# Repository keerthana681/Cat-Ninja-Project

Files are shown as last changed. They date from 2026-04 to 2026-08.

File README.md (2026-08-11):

# Cat Ninja Handheld Console Game
 
A handheld gaming console built from scratch for UT Austin's ECE319H (Introduction to Embedded Systems), featuring a custom PCB, dual-LCD displays, and an interrupt-driven game engine.
 
## Overview
 
Cat Ninja is a fully custom embedded gaming handheld built around the TI MSPM0 microcontroller. The project spans the full hardware-software stack: a custom-designed PCB, analog input sampling via joystick and slide potentiometer, a discrete DAC for in-game sound, and a real-time game engine driven by hardware timers and interrupts.
 
## Features
 
- **Custom PCB** designed in KiCad, integrating the TI MSPM0 microcontroller with dual-LCD displays and a joystick interface
- **Dual-LCD setup** — one screen renders the live game, the other displays the score and a reactive cat sprite (happy when fish are sliced, sad when a bomb is hit or a life is lost)
- **Original hand-drawn sprite art** for the cat cursor, fish, sliced-fish states, and bombs
- **Analog input sampling** via ADC for the joystick (menu navigation and cursor movement) and slide potentiometer (in-game volume control)
- **5-bit binary-weighted DAC** for real-time sound effects (slicing, explosions, and more)
- **Interrupt-driven game engine** written in C++, using SysTick and TimerG12 for periodic game logic, rendering, and input polling
- **Finite state machine (FSM) architecture** driving the title menu, settings, gameplay, pause, and game-over screens
## How to Play
 
**Menu Navigation**
- On the title screen, move the joystick to switch between **Info**, **Settings**, and **Play**
- One button **selects** the highlighted option; the other button **goes back** to the previous screen
- **Info** explains how to play
- **Settings** lets you change the display language (English/Spanish)
**Gameplay**
- Move the cat paw cursor around the screen using the joystick
- Press the select button to **slice** — this triggers a slicing sound and swaps the fish sprite to its sliced state
- Fish rise and fall across the screen at random; slice them to score points
- Bombs appear at random alongside the fish — avoid slicing these
- You have **3 lives**. You lose a life if you let a fish fall unsliced, or if you slice a bomb (which also triggers an explosion sound)
- When you run out of lives, the game ends with a crying-cat sound effect
- The volume of in-game sound effects is controlled in real time by the slide potentiometer
## Hardware
 
- TI MSPM0 microcontroller
- Dual-LCD display setup
- Joystick + slide potentiometer analog inputs
- Custom binary-weighted DAC circuit for audio output
- PCB designed and fabricated for this project (see `/hardware` for KiCad files and schematics)
## Software
 
- Core game engine written in C++
- SysTick and TimerG12 used for periodic, interrupt-driven task scheduling
- ADC driver for analog input sampling
- DAC output driver for sound playback
## Team
 
Built by Keerthana Mangalpally and Kaitlyn Chen for ECE319H at UT Austin.
 
## Acknowledgments & License
 
This project uses hardware driver code adapted from course materials provided by Dr. Jonathan Valvano for UT Austin's embedded systems curriculum, used under the license below.
 
```
Simplified BSD License (FreeBSD License)
Copyright © 2025, Jonathan Valvano, All rights reserved.
 
Redistribution and use in source and binary forms, with or without modification,
are permitted provided that the following conditions are met:
 
1. Redistributions of source code must retain the above copyright notice,
   this list of conditions and the following disclaimer.
2. Redistributions in binary form must reproduce the above copyright notice,
   this list of conditions and the following disclaimer in the documentation
   and/or other materials provided with the distribution.
 
THIS SOFTWARE IS PROVIDED BY THE COPYRIGHT HOLDERS AND CONTRIBUTORS "AS IS"
AND ANY EXPRESS OR IMPLIED WARRANTIES, INCLUDING, BUT NOT LIMITED TO, THE
IMPLIED WARRANTIES OF MERCHANTABILITY AND FITNESS FOR A PARTICULAR PURPOSE
ARE DISCLAIMED. IN NO EVENT SHALL THE COPYRIGHT OWNER OR CONTRIBUTORS BE
LIABLE FOR ANY DIRECT, INDIRECT, INCIDENTAL, SPECIAL, EXEMPLARY, OR CONSEQUENTIAL
DAMAGES (INCLUDING, BUT NOT LIMITED TO, PROCUREMENT OF SUBSTITUTE GOODS OR SERVICES;
LOSS OF USE, DATA, OR PROFITS; OR BUSINESS INTERRUPTION) HOWEVER CAUSED
AND ON ANY THEORY OF LIABILITY, WHETHER IN CONTRACT, STRICT LIABILITY,
OR TORT (INCLUDING NEGLIGENCE OR OTHERWISE) ARISING IN ANY WAY OUT OF THE
USE OF THIS SOFTWARE, EVEN IF ADVISED OF THE POSSIBILITY OF SUCH DAMAGE.
 
The views and conclusions contained in the software and documentation are
those of the authors and should not be interpreted as representing official
policies, either expressed or implied, of the FreeBSD Project.
```
 
For more information on the original course materials, see [Dr. Valvano's course page](http://users.ece.utexas.edu/~valvano/).

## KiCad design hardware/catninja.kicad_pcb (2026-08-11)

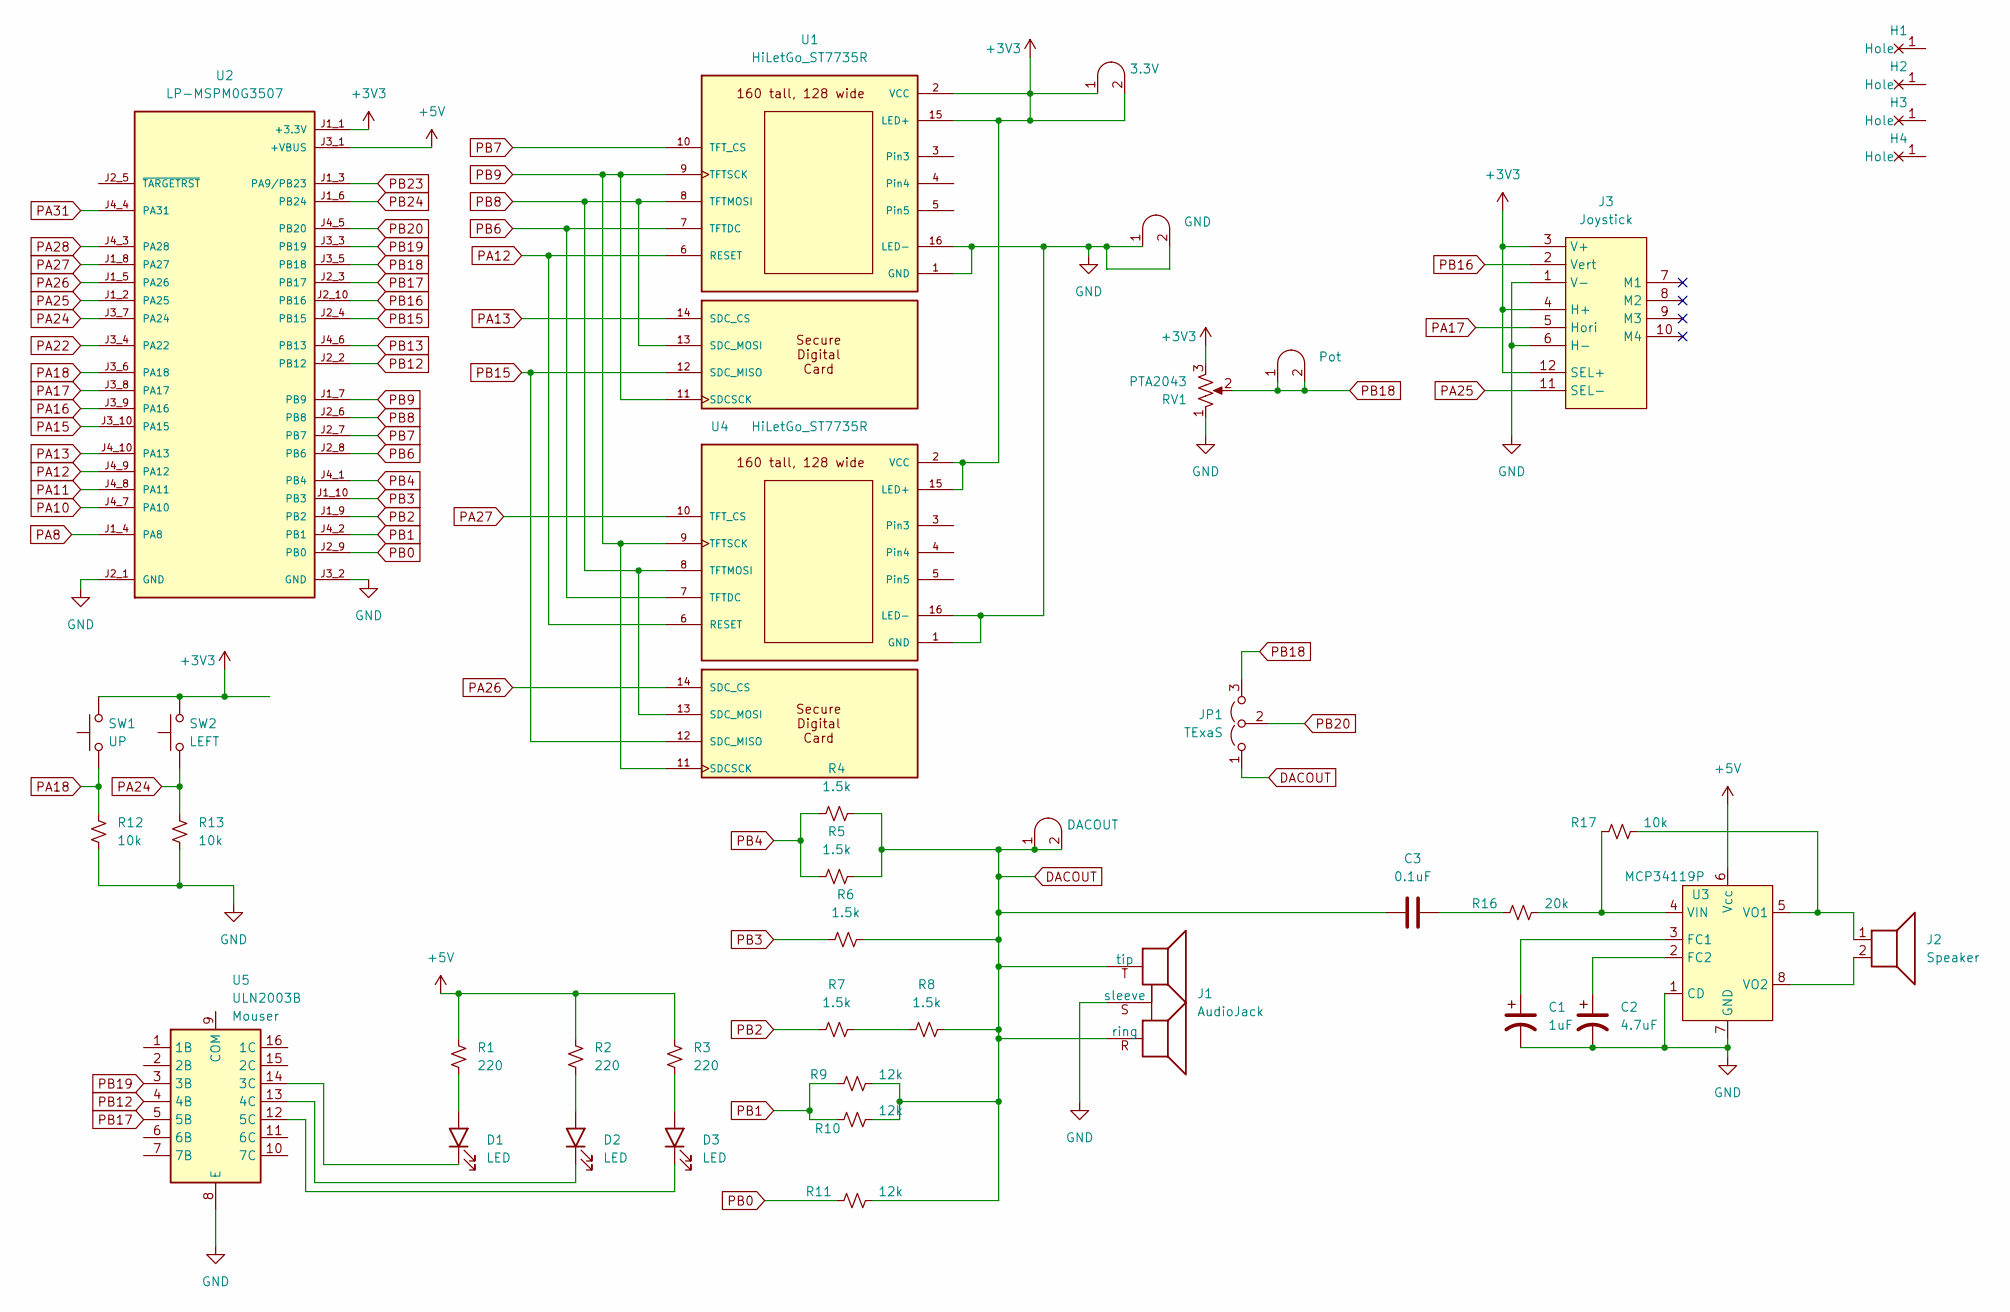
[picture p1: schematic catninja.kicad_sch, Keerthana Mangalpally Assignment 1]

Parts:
C1: 1uF; CP_Radial_Tantal200mil
C2: 4.7uF; CP_Radial_Tantal200mil
C3: 0.1uF; C_Axial_200mil
D1, D2, D3: LED; LED_D5.0mm
H1, H2, H3, H4: MountingHole_4_40
J1: AudioJack; Jack_3.5mm_CUI_SJ1-3523N_Horizontal
J2: Speaker; PinHeader_1x02_P2.54mm_Vertical
J3: Joystick; SparkfunJoystick
J4: Pot; Testpoint_1x02_P2.54mm
J6: GND; Testpoint_1x02_P2.54mm
J7: DACOUT; Testpoint_1x02_P2.54mm
JP1: TExaS; PinHeader_1x03_P2.54mm_Vertical
R1, R2, R3: 220; R_Axial_DIN0204_L3.6mm_D1.6mm_P7.62mm_Horizontal
R4, R5, R6, R7, R8: 1.5k; R_Axial_DIN0204_L3.6mm_D1.6mm_P7.62mm_Horizontal
R9, R10, R11: 12k; R_Axial_DIN0204_L3.6mm_D1.6mm_P7.62mm_Horizontal
R12, R13, R17: 10k; R_Axial_DIN0204_L3.6mm_D1.6mm_P7.62mm_Horizontal
R16: 20k; R_Axial_DIN0204_L3.6mm_D1.6mm_P7.62mm_Horizontal
RV1: PTA2043; PTA2043pot
SW1: UP; SW_PUSH_6mm
SW2: LEFT; SW_PUSH_6mm
TP1: 3.3V; Testpoint_1x02_P2.54mm
U1, U4: HiLetGo_ST7735R; hiletgo_st7735r
U2: LP-MSPM0G3507; ti_LP_MSPM0G3507
U3: MCP34119P; DIP-8_W7.62mm_LongPads
U5: ULN2003B; DIP-16_W7.62mm

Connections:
+3V3: J3.3 (V+), J3.4 (H+), J3.12 (SEL+), RV1.3, SW1.2, SW2.2, TP1.1 (A), TP1.2 (B), U1.2 (VCC), U1.15 (LED+), U2.J1_1 (+3.3V), U4.2 (VCC), U4.15 (LED+)
+5V: R1.1, R2.1, R3.1, U2.J3_1 (+VBUS), U3.6 (Vcc)
DACOUT: C3.1, J1.R (ring), J1.T (tip), J7.1 (A), J7.2 (B), JP1.1 (A), R4.1, R5.1, R6.1, R8.1, R9.1, R10.1, R11.1
GND: C1.2, C2.2, J1.S (sleeve), J3.1 (V-), J3.6 (H-), J6.1 (A), J6.2 (B), R12.2, R13.2, RV1.1, U1.1 (GND), U1.16 (LED-), U2.J2_1 (GND), U2.J3_2 (GND), U3.1 (CD), U3.7 (GND), U4.1 (GND), U4.16 (LED-), U5.8 (E)
unnamed: C3.2, R16.2
unnamed: D1.2 (A), R1.2
unnamed: D1.1 (K), U5.14 (3C)
unnamed: D2.2 (A), R2.2
unnamed: D2.1 (K), U5.13 (4C)
unnamed: D3.2 (A), R3.2
unnamed: D3.1 (K), U5.12 (5C)
unnamed: R7.1, R8.2
unnamed: C1.1, U3.3 (FC1)
unnamed: C2.1, U3.2 (FC2)
unnamed: R16.1, R17.2, U3.4 (VIN)
unnamed: J2.1, R17.1, U3.5 (VO1)
unnamed: J2.2, U3.8 (VO2)
PA8: U2.J1_4 (PA8)
PA10: U2.J4_7 (PA10)
PA11: U2.J4_8 (PA11)
PA12: U1.6 (RESET), U2.J4_9 (PA12), U4.6 (RESET)
PA13: U1.14 (SDC_CS), U2.J4_10 (PA13)
PA15: U2.J3_10 (PA15)
PA16: U2.J3_9 (PA16)
PA17: J3.5 (Hori), U2.J3_8 (PA17)
PA18: R12.1, SW1.1, U2.J3_6 (PA18)
PA22: U2.J3_4 (PA22)
PA24: R13.1, SW2.1, U2.J3_7 (PA24)
PA25: J3.11 (SEL-), U2.J1_2 (PA25)
PA26: U2.J1_5 (PA26), U4.14 (SDC_CS)
PA27: U2.J1_8 (PA27), U4.10 (TFT_CS)
PA28: U2.J4_3 (PA28)
PA31: U2.J4_4 (PA31)
PB0: R11.2, U2.J2_9 (PB0)
PB1: R9.2, R10.2, U2.J4_2 (PB1)
PB2: R7.2, U2.J1_9 (PB2)
PB3: R6.2, U2.J1_10 (PB3)
PB4: R4.2, R5.2, U2.J4_1 (PB4)
PB6: U1.7 (TFTDC), U2.J2_8 (PB6), U4.7 (TFTDC)
PB7: U1.10 (TFT_CS), U2.J2_7 (PB7)
PB8: U1.8 (TFTMOSI), U1.13 (SDC_MOSI), U2.J2_6 (PB8), U4.8 (TFTMOSI), U4.13 (SDC_MOSI)
PB9: U1.9 (TFTSCK), U1.11 (SDCSCK), U2.J1_7 (PB9), U4.9 (TFTSCK), U4.11 (SDCSCK)
PB12: U2.J2_2 (PB12), U5.4 (4B)
PB13: U2.J4_6 (PB13)
PB15: U1.12 (SDC_MISO), U2.J2_4 (PB15), U4.12 (SDC_MISO)
PB16: J3.2 (Vert), U2.J2_10 (PB16)
PB17: U2.J2_3 (PB17), U5.5 (5B)
PB18: J4.1 (A), J4.2 (B), JP1.3 (B), RV1.2, U2.J3_5 (PB18)
PB19: U2.J3_3 (PB19), U5.3 (3B)
PB20: JP1.2 (C), U2.J4_5 (PB20)
PB23: U2.J1_3 (PA9/PB23)
PB24: U2.J1_6 (PB24)

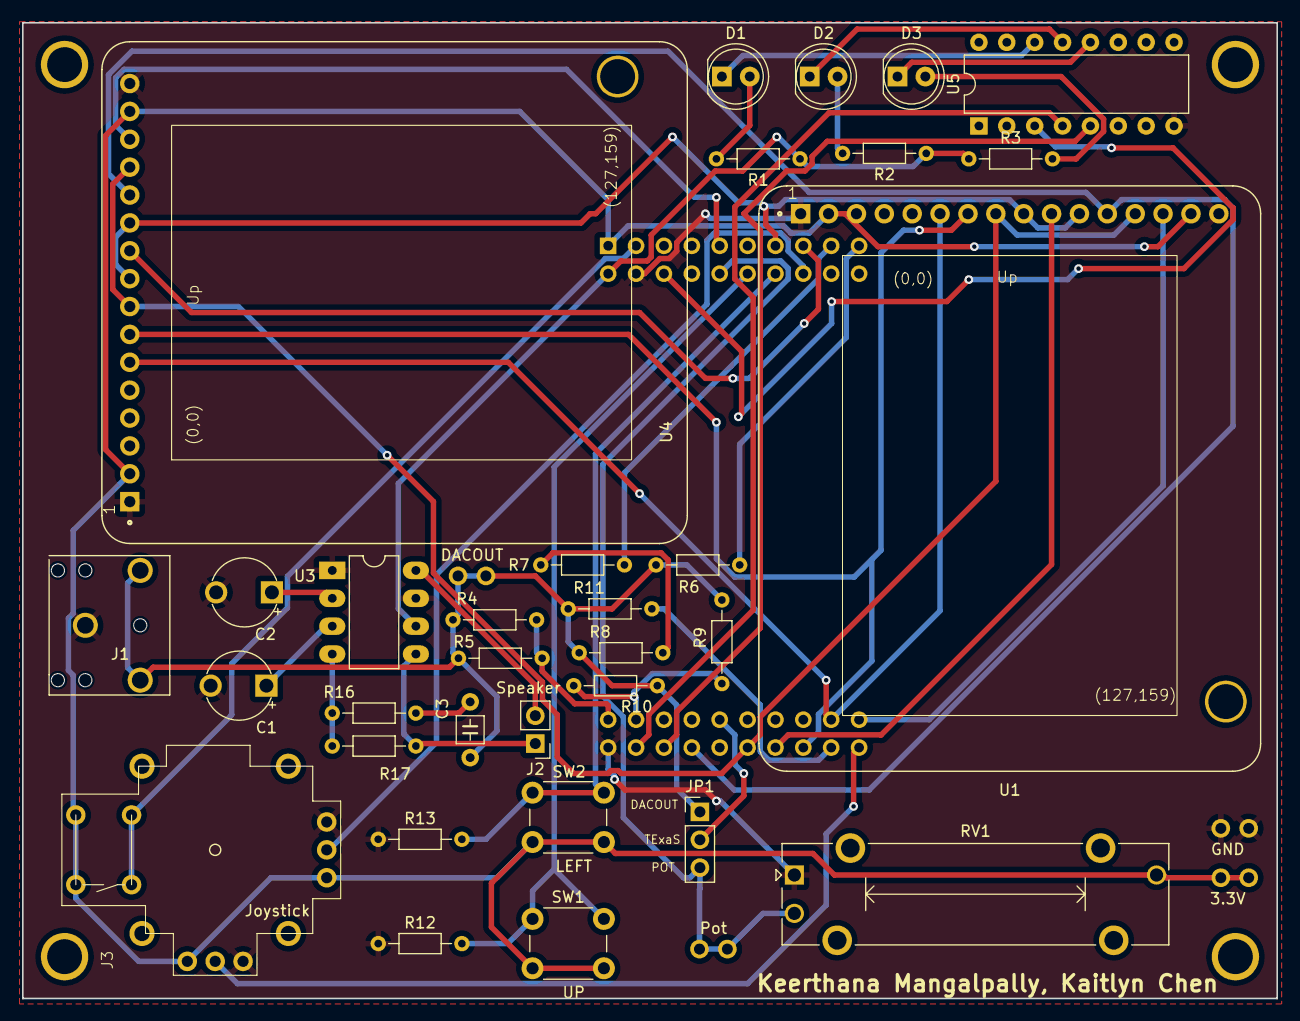
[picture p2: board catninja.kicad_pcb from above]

Board: 2 copper layers, 114.3 x 88.9 mm, 41 parts (1 on the bottom side), 41 nets.

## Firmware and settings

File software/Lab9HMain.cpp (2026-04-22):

// Lab9HMain.cpp
// Runs on MSPM0G3507
// Lab 9 ECE319H
// Kaitlyn Chen
// Last Modified: April 21, 2026

//made files
#include "game.h"
#include "LCD2.h"

#include <stdio.h>
#include <stdint.h>
#include <ti/devices/msp/msp.h>
#include "../inc/ST7735.h"
#include "../inc/Clock.h"
#include "../inc/LaunchPad.h"
#include "../inc/TExaS.h"
#include "../inc/Timer.h"
#include "../inc/SlidePot.h"
#include "../inc/DAC5.h"
// #include "SmallFont.h"
#include "LED.h"
#include "Switch.h"
#include "Sound.h"
#include "images/images.h"
#include "Timer.h"
#include "JoyStick.h"
#include "../inc/SPI.h"

extern "C" void __disable_irq(void);
extern "C" void __enable_irq(void);
extern "C" void TIMG12_IRQHandler(void);

extern "C" {
    #include "ADC.h" 
}

// Fault diagnostics exposed as globals for the debugger.
// If execution lands in a fault/default handler, inspect these values first.
extern "C" volatile uint32_t g_fault_vector = 0;
extern "C" volatile uint32_t g_fault_pc = 0;
extern "C" volatile uint32_t g_fault_lr = 0;
extern "C" volatile uint32_t g_fault_sp = 0;
extern "C" volatile uint32_t g_fault_ipsr = 0;
extern "C" volatile uint32_t g_fault_xpsr = 0;

extern "C" void Fault_Capture(uint32_t *sp){
  g_fault_sp = (uint32_t)sp;
  g_fault_ipsr = __get_IPSR();
  g_fault_vector = g_fault_ipsr & 0x1FFu;
  if(sp){
    g_fault_pc = sp[6];   // stacked PC
    g_fault_lr = sp[5];   // stacked LR
    g_fault_xpsr = sp[7]; // stacked xPSR
  }else{
    g_fault_pc = 0;
    g_fault_lr = 0;
    g_fault_xpsr = 0;
  }
}

extern "C" void HardFault_Handler(void){
  __disable_irq();
  Fault_Capture((uint32_t *)__get_MSP());
  while(1){
  }
}

extern "C" void Default_Handler(void){
  __disable_irq();
  Fault_Capture((uint32_t *)__get_MSP());
  while(1){
  }
}
// ****note to ECE319K students****
// the data sheet says the ADC does not work when clock is 80 MHz
// however, the ADC seems to work on my boards at 80 MHz
// I suggest you try 80MHz, but if it doesn't work, switch to 40MHz
void PLL_Init(void){ // set phase lock loop (PLL)
  // Clock_Init40MHz(); // run this line for 40MHz
  Clock_Init80MHz();   // run this line for 80MHz
}

uint32_t M=1;
uint32_t Random32(void){
  M = 1664525*M+1013904223;
  return M;
}
uint32_t Random(uint32_t n){
  return (Random32()>>16)%n;
}

SlidePot Sensor(1500,0); // copy calibration from Lab 7

// games  engine runs at 30Hz
extern "C" void TIMG12_IRQHandler(void){uint32_t pos,msg;
  if((TIMG12->CPU_INT.IIDX) == 1){ // this will acknowledge
    GPIOB->DOUTTGL31_0 = GREEN; // toggle PB27 (minimally intrusive debugging)
    GPIOB->DOUTTGL31_0 = GREEN; // toggle PB27 (minimally intrusive debugging)
// game engine goes here
    // 1) sample slide pot
    // 2) read input switches
    // 3) move sprites
    // 4) start sounds
    // 5) set semaphore
    // NO LCD OUTPUT IN INTERRUPT SERVICE ROUTINES
    Semaphore = 1;
    GPIOB->DOUTTGL31_0 = GREEN; // toggle PB27 (minimally intrusive debugging)
  }
}
uint8_t TExaS_LaunchPadLogicPB27PB26(void){
  return (0x80|((GPIOB->DOUT31_0>>26)&0x03));
}

typedef enum {English, Spanish, Portuguese, French} Language_t;
Language_t myLanguage=English;
typedef enum {HELLO, GOODBYE, LANGUAGE} phrase_t;
const char Hello_English[] ="Hello";
const char Hello_Spanish[] ="\xADHola!";
const char Hello_Portuguese[] = "Ol\xA0";
const char Hello_French[] ="All\x83";
const char Goodbye_English[]="Goodbye";
const char Goodbye_Spanish[]="Adi\xA2s";
const char Goodbye_Portuguese[] = "Tchau";
const char Goodbye_French[] = "Au revoir";
const char Language_English[]="English";
const char Language_Spanish[]="Espa\xA4ol";
const char Language_Portuguese[]="Portugu\x88s";
const char Language_French[]="Fran\x87" "ais";
const char *Phrases[3][4]={
  {Hello_English,Hello_Spanish,Hello_Portuguese,Hello_French},
  {Goodbye_English,Goodbye_Spanish,Goodbye_Portuguese,Goodbye_French},
  {Language_English,Language_Spanish,Language_Portuguese,Language_French}
};
// use main1 to observe special characters
int main1(void){ // main1
    char l;
  __disable_irq();
  PLL_Init(); // set bus speed
  LaunchPad_Init();
  ST7735_InitPrintf(INITR_BLACKTAB); // INITR_REDTAB for AdaFruit, INITR_BLACKTAB for HiLetGo
  ST7735_FillScreen(0x0000);            // set screen to black
  for(int myPhrase=0; myPhrase<= 2; myPhrase++){
    for(int myL=0; myL<= 3; myL++){
         ST7735_OutString((char *)Phrases[LANGUAGE][myL]);
      ST7735_OutChar(' ');
         ST7735_OutString((char *)Phrases[myPhrase][myL]);
      ST7735_OutChar(13);
    }
  }
  Clock_Delay1ms(3000);
  ST7735_FillScreen(0x0000);       // set screen to black
  l = 128;
  while(1){
    Clock_Delay1ms(2000);
    for(int j=0; j < 3; j++){
      for(int i=0;i<16;i++){
        ST7735_SetCursor(7*j+0,i);
        ST7735_OutUDec(l);
        ST7735_OutChar(' ');
        ST7735_OutChar(' ');
        ST7735_SetCursor(7*j+4,i);
        ST7735_OutChar(l);
        l++;
      }
    }
  }
}

// // use main2 to observe graphics
// int main2(void){ // main2
//   __disable_irq();
//   PLL_Init(); // set bus speed
//   LaunchPad_Init();
//   ST7735_InitPrintf(INITR_BLACKTAB); // INITR_REDTAB for AdaFruit, INITR_BLACKTAB for HiLetGo
//   ST7735_FillScreen(ST7735_BLACK);
//   // ST7735_DrawBitmap(22, 159, PlayerShip0, 18,8); // player ship bottom
//   // ST7735_DrawBitmap(53, 151, Bunker0, 18,5);
//   // ST7735_DrawBitmap(42, 159, PlayerShip1, 18,8); // player ship bottom
//   // ST7735_DrawBitmap(62, 159, PlayerShip2, 18,8); // player ship bottom
//   // ST7735_DrawBitmap(82, 159, PlayerShip3, 18,8); // player ship bottom
//   // ST7735_DrawBitmap(0, 9, SmallEnemy10pointA, 16,10);
//   // ST7735_DrawBitmap(20,9, SmallEnemy10pointB, 16,10);
//   // ST7735_DrawBitmap(40, 9, SmallEnemy20pointA, 16,10);
//   // ST7735_DrawBitmap(60, 9, SmallEnemy20pointB, 16,10);
//   // ST7735_DrawBitmap(80, 9, SmallEnemy30pointA, 16,10);

//   for(uint32_t t=500;t>0;t=t-5){
//     SmallFont_OutVertical(t,104,6); // top left
//     Clock_Delay1ms(50);              // delay 50 msec
//   }
//   ST7735_FillScreen(0x0000);   // set screen to black
//   ST7735_SetCursor(1, 1);
//   ST7735_OutString((char *)"GAME OVER");
//   ST7735_SetCursor(1, 2);
//   ST7735_OutString((char *)"Nice try,");
//   ST7735_SetCursor(1, 3);
//   ST7735_OutString((char *)"Earthling!");
//   ST7735_SetCursor(2, 4);
//   ST7735_OutUDec(1234);
//   while(1){
//   }
// }

// use main3 to test switches and LEDs
int main3(void){ // main3
  __disable_irq();
  PLL_Init(); // set bus speed
  LaunchPad_Init();
  Switch_Init(); // initialize switches
  LED_Init(); // initialize LED
  while(1){
    // write code to test switches and LEDs

  }
}
// use main4 to test sound outputs
// int main4(void){ uint32_t last1=0,last2=0;
//   __disable_irq();
//   PLL_Init(); // set bus speed
//   LaunchPad_Init();
//   Switch_Init(); // initialize switches
//   LED_Init(); // initialize LED
//   Sound_Init();  // initialize sound
//   TExaS_Init(ADC0,6,0); // ADC1 channel 6 is PB20, TExaS scope
//   __enable_irq();
//   while(1){
//     uint8_t btn1 = (GPIOA->DIN31_0 >> 24) & 0x01;
//     uint8_t btn2 = (GPIOA->DIN31_0 >> 25) & 0x01;
//     if((last1 == 0)&&(btn1 == 1)){
//       Sound_Shoot();
//     }
//     if((last2 == 0)&&(btn2 == 1)){
//       Sound_Killed();
//     }
//     last1 = btn1;
//     last2 = btn2;
//   }
// }
//tests led functions 
int main8(void){
    __disable_irq();
    PLL_Init();
    LaunchPad_Init();
    LED_Init();
    __enable_irq();

    while(1){
        LED_SetLives(3);
        Clock_Delay1ms(500);
        LED_SetLives(2);
        Clock_Delay1ms(500);
        LED_SetLives(1);
        Clock_Delay1ms(500);
        LED_SetLives(0);
        Clock_Delay1ms(500);
    }
}
int main7(void){
    __disable_irq();
    PLL_Init();
    LaunchPad_Init();

    // LED pins: PB19, PB12, PB17 through ULN2003B
    IOMUX->SECCFG.PINCM[44] = 0x00000081;  // PB19
    IOMUX->SECCFG.PINCM[28] = 0x00000081;  // PB12
    IOMUX->SECCFG.PINCM[42] = 0x00000081;  // PB17
    GPIOB->DOE31_0 |= (1<<19) | (1<<12) | (1<<17);

    __enable_irq();

    // turn all on
    GPIOB->DOUTSET31_0 = (1<<19) | (1<<12) | (1<<17);

    while(1){
        GPIOB->DOUTTGL31_0 = (1<<19) | (1<<12) | (1<<17);
        Clock_Delay1ms(500);
    }
}
int main6(void){
    __disable_irq();
    PLL_Init();
    LaunchPad_Init();
    // configure PA15 as GPIO output
    IOMUX->SECCFG.PINCM[PA15INDEX] = 0x00000081;
    GPIOA->DOE31_0 |= (1<<15);
    __enable_irq();
    
    while(1){
        GPIOA->DOUTTGL31_0 = (1<<15); // toggle PA15
        Clock_Delay1ms(1); // ~500 Hz buzz
    }
}

int main9(void){
    __disable_irq();
    PLL_Init();
    LaunchPad_Init();
    ST7735_InitPrintf(INITR_BLACKTAB);
    // LCD2_Init();
    __enable_irq();

    while(1){
        SPI_SelectDisplay(SPI_DISPLAY_LCD1);
        ST7735_SetRotation(1);
        ST7735_FillScreen(ST7735_RED);
        ST7735_SetCursor(2, 2);
        ST7735_SetTextColor(ST7735_WHITE);
        ST7735_OutString((char*)"LCD1 ONLY");
        Clock_Delay1ms(1000);

        SPI_SelectDisplay(SPI_DISPLAY_LCD2);
        LCD2_FillScreen(LCD2_BLUE);
        Clock_Delay1ms(1000);
    }
}

// ALL ST7735 OUTPUT MUST OCCUR IN MAIN
// NOTE: ADC.h is already included above (wrapped in extern "C") — no second include needed.

int main(void){
    __disable_irq();
    PLL_Init();
    LaunchPad_Init();
    ST7735_InitPrintf(INITR_BLACKTAB);
    SPI_SelectDisplay(SPI_DISPLAY_LCD1);
    ST7735_SetRotation(1);
    ST7735_FillScreen(ST7735_BLACK);
    Sensor.Init();
    Switch_Init();
    LED_Init();
    Sound_Init();
    TExaS_Init(0,0,&TExaS_LaunchPadLogicPB27PB26);
    TimerG12_IntArm(80000000/30, 2);
    LCD2_Init();   // second display (portrait, PA26 CS) — must come after ST7735_InitPrintf
    Game_Init();
    Semaphore = 1; // render the first frame even if the timer has not fired yet
    __enable_irq();

    while(1){
      if(Semaphore){
        Semaphore = 0;
      } else {
        // Fall back to software pacing so startup does not deadlock if TIMG12 does not tick yet.
        Clock_Delay1ms(33);
      }

      // Read slide pot without resetting ADC1 (a full reset breaks the joystick).
      Sound_SetVolume(Joystick_ReadSlidePot());

      SPI_SelectDisplay(SPI_DISPLAY_LCD1);
      Game_UpdateFrame();

      uint32_t Input  = Game_GetInput();
      uint32_t nextS  = FSM[S].Next[Input];

      // Play meow whenever the player navigates to a new screen,
      // but not on game-over (Sound_Sad starts there instead).
      if(nextS != S && nextS != S_GAMEOVER){
          Sound_Meow();
      }

      S = nextS;
    }
}

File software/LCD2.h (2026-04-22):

// LCD2.h
// Driver for the second ST7735 display (portrait orientation, 128x160).
// Shares SPI1 (PB8=MOSI, PB9=SCLK, PA13=DC, PB15=RESET) with LCD1.
// LCD1 chip-select stays on PB6, LCD2 chip-select is PA26 (PINCM index 58), active-low.
// LCD2 is vertical — used for score, lives, and reaction faces.
//
// Kaitlyn Chen and Keerthana Mangalpally
// ECE319H Lab 9, Spring 2026

#ifndef LCD2_H
#define LCD2_H
#include <stdint.h>

// ── Color constants (16-bit RGB565, same encoding as ST7735) ─────────────
#define LCD2_BLACK    0x0000
#define LCD2_WHITE    0xFFFF
#define LCD2_RED      0x001F
#define LCD2_GREEN    0x07E0
#define LCD2_BLUE     0xF800
#define LCD2_CYAN     0xFFE0
#define LCD2_YELLOW   0x07FF
#define LCD2_MAGENTA  0xF81F
#define LCD2_ORANGE   0x041F
#define LCD2_DARKGREY 0x39E7

// ── LCD2 display dimensions (portrait mode) ───────────────────────────────
#define LCD2_WIDTH   128
#define LCD2_HEIGHT  160

// ── Public API ────────────────────────────────────────────────────────────

// Initialize LCD2 hardware (PA26 GPIO + ST7735 init sequence, portrait mode).
// Must be called AFTER ST7735_InitR/InitPrintf (which sets up SPI1).
void LCD2_Init(void);

// Fill the entire display with a solid color.
void LCD2_FillScreen(uint16_t color);

// Display the current score as large 7-segment-style digits.
// score: 0 to 9999 (values >= 1000 show 4 digits).
void LCD2_ShowScore(uint32_t score);

// Display lives remaining as colored indicator squares (3 squares max).
// lives: 0-3 (0 = all grey, 3 = all red).
void LCD2_ShowLives(uint8_t lives);

// Draw a cat sprite in the bottom panel (y=88-160), centered horizontally.
// The caller (game.cpp) selects the sprite to avoid duplicating rodata here.
void LCD2_ShowReaction(const unsigned short *img, int16_t w, int16_t h);

// Display the current difficulty level (0-9) at the bottom of the portrait display.
// Call during gameplay whenever the level changes.
void LCD2_ShowLevel(uint8_t level);

// Show a "PAUSED" indicator in the cat panel (replaces sleeping_cat sprite).
void LCD2_ShowPaused(void);

#endif // LCD2_H

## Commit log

2026-04-22 Add initial project files
    [ColorConvert5-6-5.xlsx, trig.xlsx]
2026-04-22 fixed sound output interactions + slidepot
    [LCD2.cpp, LCD2.h, Sound.cpp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]
2026-08-11 Reorganize project structure
    [catninja.kicad_pcb, catninja.kicad_sch]
